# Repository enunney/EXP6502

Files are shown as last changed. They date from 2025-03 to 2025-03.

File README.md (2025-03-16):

# EXP6502
6502 based expandable computer.

<p align="center">
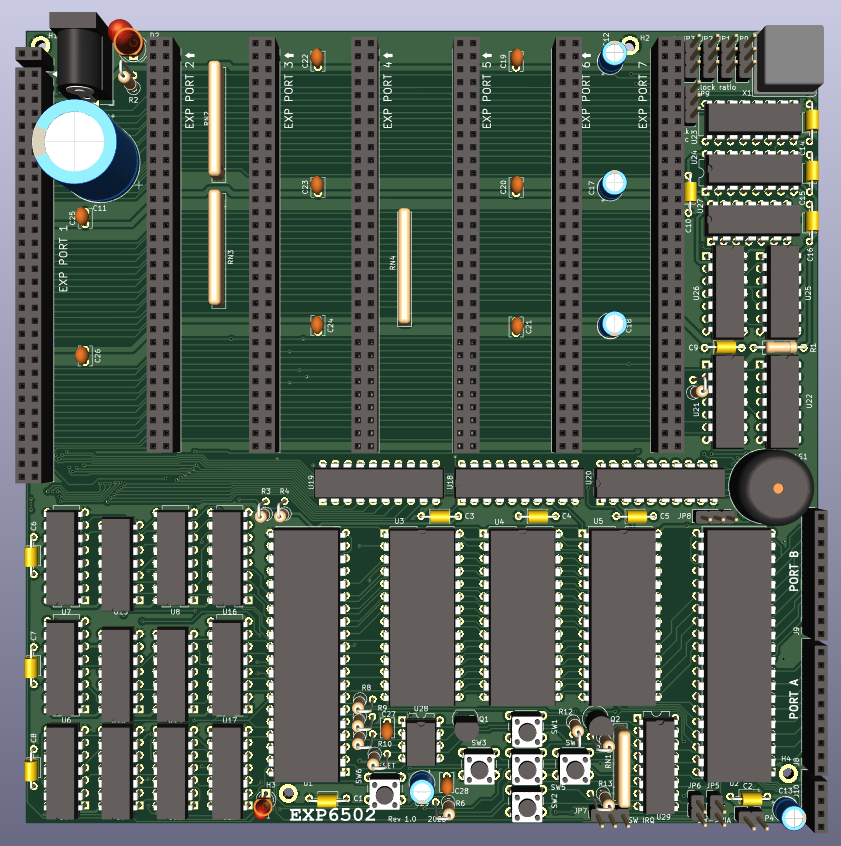
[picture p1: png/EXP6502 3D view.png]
  
</p>

## Specifications

- W65C02 CPU @ 8MHz
- 64 kB SRAM
- 32 kB EEPROM (read only)
- 7 general purpose expansion ports
- Bank switching with access to up to 160 kB of memory
- W65C22 Versatile Interface Adapter
- Software controllable glitchless clock switching (8 MHz / fraction of 8 MHz)
- Built-in beeper speaker and LED
- 5 built-in push buttons with interrupt capability

## Architecture
### Block diagram

<p align="center">
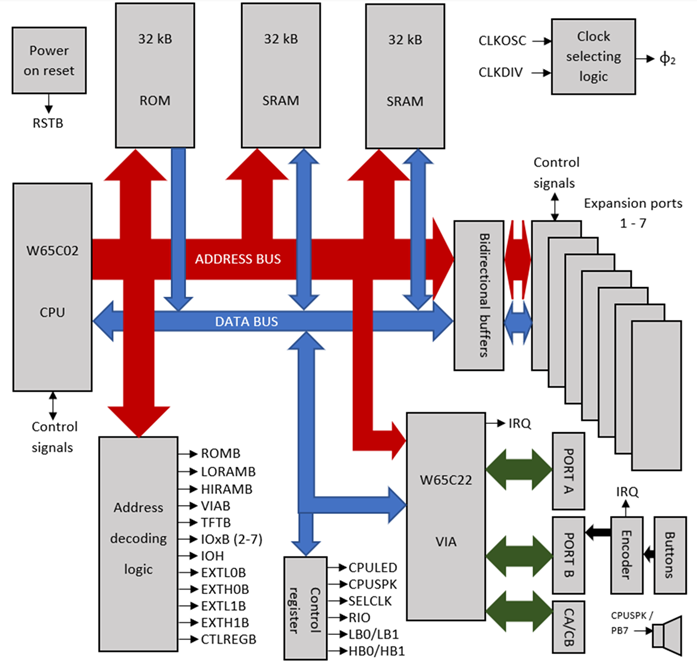
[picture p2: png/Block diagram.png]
  
</p>

The CPU address and data buses are directly connected to the onboard memory and peripherals. Tristate buffers isolate the local buses from the expansion ports.
CMOS logic ICs decode the address bus as well as the status of the control register to provide control signals for each component.

### Memory map

<p align="center">
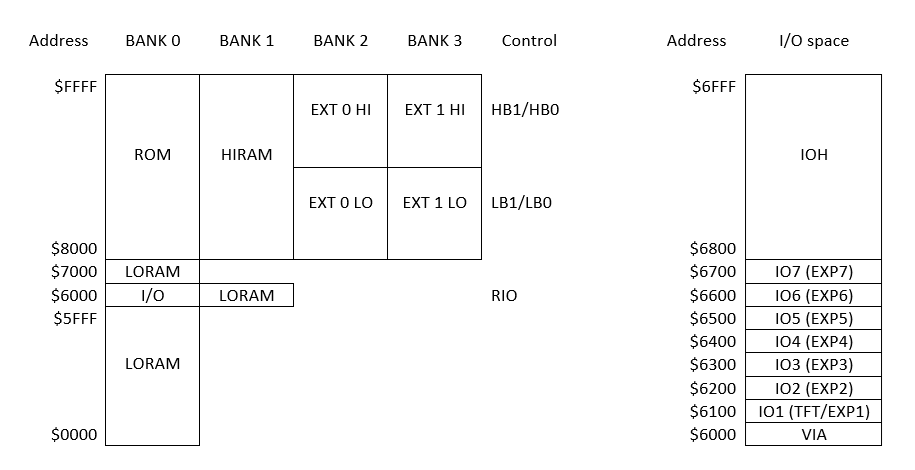
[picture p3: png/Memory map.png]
  
</p>

The lower half of the address space contains 32 kB of RAM (the low RAM) and the I/O space. The I/O space sits
between $6000 and $6FFF. It can be switched out to access the 4 kB of RAM located at the same memory addresses.

The I/O space is made of two parts. The bottom one is divided in 8 pages, each of these controlling one I/O
peripheral. The first I/O page is reserved for the built in VIA. The 7 others are each attributed to a different
expansion port. The top part of the I/O space, IOH, is available on every expansion port, in case they need more I/O
addresses.

The upper half of the address space is divided in two blocks, each of them is multiplied in 4 banks. One bank in each
block can be selected at a time, and the two blocks can have a different bank selected.

The first bank gives access to the ROM of the computer, it is selected by default at start up or after reset.
The second one gives access to 32 kB of RAM, the high RAM.
The third and fourth ones give access to memory placed on the expansion ports. The chip select signals of these
banks are accessible on any expansion port.

The bank switching in the lower half of the address space is controlled by the RIO signal, bit 3 of the control register.
It allows switching the window between $6000 and $6FFF to the I/O space, when RIO is low, or to the low RAM,
when RIO is high.

The bank switching in the upper half of the address space is controlled by the LB0, LB1, HB0 and HB1 signals, bits 4 to
7 of the control register. The bits LB0 and LB1 control the bank switching in the bottom block (\$8000 to \$BFFF). HB0
and HB1 control the switching in the top block (\$C000 to \$FFFF).
- The first bank, bank 0, is mapped to the ROM, in the two blocks.
- The bank 1, is mapped in the two blocks to the high RAM.
- The bank 2 enables the external high memory 0, EXT0HI in the top block and the external low memory 0, EXT0LO in the bottom block.
- The bank 3 enables the external high memory 1, EXT1HI in the top block and the external low memory 1, EXT1LO in the bottom block.

### Expansion port

The computer has 7 general purpose expansion ports.
They give access to buffered versions of the address and data buses of the computer, to various control signals of
the microprocessor and to the selecting signals for the external memory banks. They also have access to some pins
of the VIA.

The expansion ports have access to the main clock, φ2, as well as the oscillator clock and the divided clock. This
feature allows an expansion card to keep using one of these clocks while the computer has switched to another one,
for instance for slow peripherals that couldn’t handle the oscillator frequency. It is worth noting that the CPU can’t
access these peripherals while the clocks are different, as it would have an unpredictable behavior.

Any expansion port can take control of the computer, by setting low the EXTCTLB signal, which disables the busses of
the CPU and reverses the direction of the address and data buffers. The RDY signal should be put low at the same
time to effectively halt the CPU.

The expansion port 1 has an additional two pins header socket placed next to it. It is intended to be connected to the
read and write pins of a TFT LCD screen (controlled by an ILI9341 IC or compatible) for write only access when the
port 1 is connected to such a screen.

The pinout of the expansion ports and the function of each pin can be found in the technical reference manual.

### Control register

The control register allows the software to switch the memory banks, to change the clock speed and to directly
control an LED and the beeper speaker.
It is located at address $0000 of the address space, in the zero page of the 6502 microprocessor, to allow faster
access.
The function of each of its bits is given below:

- Bit 0: CPULED
→ Control signal for the built in LED.
- Bit 1: CPUSPK
→ Can be connected to the built in beeper speaker.
- Bit 2: SELCLK
→ Control the current clock source for the main clock φ2.
- Bit 3: RIO
→ Select the I/O space or the low RAM between $6000 and $6FFF.
- Bit 4: LB0
→ LSB of the number of the selected bank in the bottom block of the upper half of the address space.
- Bit 5: LB1
→ MSB of the number of the selected bank in the bottom block of the upper half of the address space.
- Bit 6: HB0
→ LSB of the number of the selected bank in the top block of the upper half of the address space.
- Bit 7: HB1
→ MSB of the number of the selected bank in the top block of the upper half of the address space.

More details are available in the technical reference manual.

### Clocking

The main clock of the computer, φ2, can be switched between two different sources: the oscillator clock or a divided
version of the oscillator clock.

The default oscillator frequency is 8 MHz. A counter and a JK flip-flop generate a divided version of this clock. The
dividing ratio can be configured with 4 jumpers on the computer. The ratio is between /2 when the value configured
by the jumpers is set to 15, and /32 when the value is 0.
The dividing ratio follows the formula: R = 2*(16-n), where n is the value configured with the jumpers.

The oscillator clock can also be replaced by an external clock, placed on any of the expansion port. The external clock
must be selected with the corresponding jumper.

### I/O

The computer has a built in Versatile Interface Adapter (VIA), of which the two GPIO ports are accessible on 2 pin
header sockets. The CA1, CA2, CB1 and CB2 pins of the VIA are accessible on another pin header socket, as well as on
every expansion port.

The bits 3, 4 and 5 of the PORT B of the VIA can be connected to an 8 to 3 priority encoder with jumpers. The inputs
of the encoder are driven by 5 push buttons. When a button is pressed, the corresponding code is sent to the VIA.
The encoder can generate an interrupt either directly or through the CA2 pin of the VIA, depending on the jumper
configuration.

The VIA can also drive the built in beeper speaker when the jumper connected to the speaker is set accordingly.
The control register is connected to the red LED and can be connected to the speaker.

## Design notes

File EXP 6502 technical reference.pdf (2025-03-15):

# EXP 6502

# Technical reference

v1.0 | 12/04/2023 | Eric Nunney

## Table of contents

## I. Specifications II. Architecture

### 1. Block diagram 2. Memory map 3. Bank switching 4. Control register 5. Clock switching 6. Expansion ports 7. Built-in I/O

## III. Schematic diagram

### 1. CPU and memory 2. Address decoding

3. I/O

### 4. Expansion ports 5. Clock and reset 6. Power

## IV. PCB layout

### 1. Top layer 2. Bottom layer 3. Jumper configuration

# I. Specifications

- W65C02 microprocessor at up to 8 MHz (MOS 6502 compatible)
- 64 kB SRAM
- 32 kB EEPROM (read only)
- W65C22 Versatile Interface Adapter
- 7 general purpose expansion ports
- Bank switching, access to up to 160 kB of memory
- Software controllable glitchless clock switching (8 MHz / configurable fraction of 8 MHz)
- Power-on reset circuit
- Built-in beeper speaker
- Built-in LED
- 5 built-in push buttons with interrupt capability
- Single 5V DC power input
- CMOS only logic ICs (higher speed / less power)

# II. Architecture

## 1. Block diagram

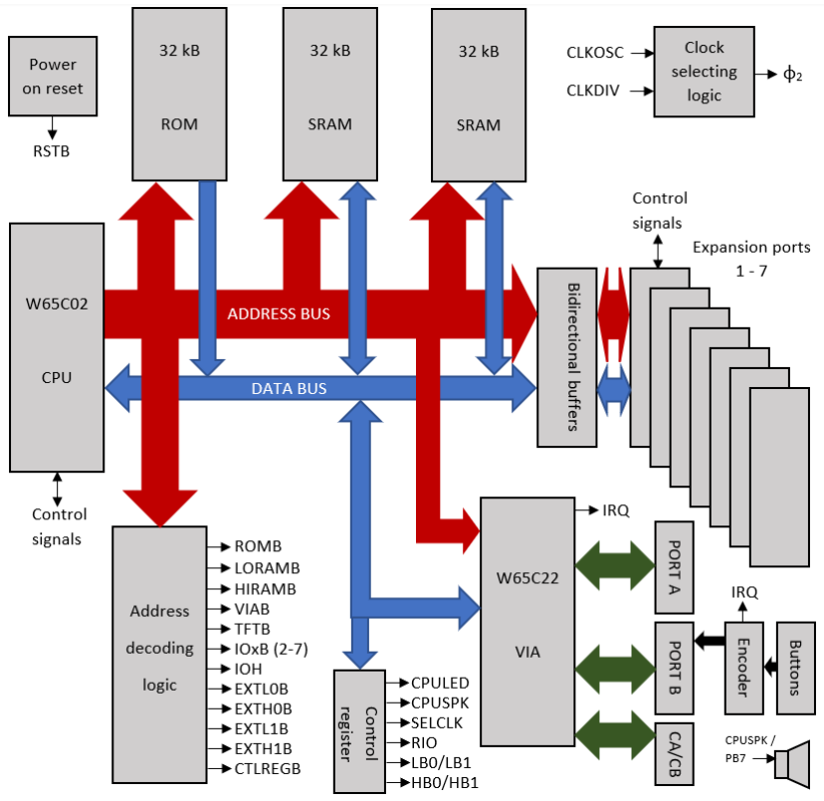
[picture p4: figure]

## 2. Memory map

Address | BANK 0 | BANK 1 | BANK 2 | BANK 3 | Control | Address | I/O space

$FFFF

ROM | HIRAM
EXT 0 HI | EXT 1 HI

$6FFF

IOH

HB1/HB0

EXT 0 LO | EXT 1 LO | LB1/LB0
$8000 | | | | $6800
$7000 | LORAM | | | $6700 | IO7 (EXP7)
$6000 | I/O | LORAM | RIO | $6600 | IO6 (EXP6)
$5FFF
| LORAM | | | $6500 | IO5 (EXP5)
| | | | $6400 | IO4 (EXP4)
| | | | $6300 | IO3 (EXP3)
| | | | $6200 | IO2 (EXP2)
| | | | $6100 | IO1 (TFT/EXP1)
$0000 | | | | $6000 | VIA

The lower half of the address space contains 32 kB of RAM (the low RAM) and the I/O space. The I/O space sits between $6000 and $6FFF. It can be switched out to access the 4 kB of RAM located at the same memory addresses.

The I/O space is made of two parts. The bottom one is divided in 8 pages, each of these controlling one I/O peripheral. The first I/O page is reserved for the built in VIA. The 7 others are each attributed to a different expansion port. The top part of the I/O space, IOH, is available on every expansion port, in case they need more I/O addresses.

The upper half of the address space is divided in two blocks, each of them is multiplied in 4 banks. One bank in each block can be selected at a time, and the two blocks can have a different bank selected.

The first bank gives access to the ROM of the computer, it is selected by default at start up or after reset.

The second one gives access to 32 kB of RAM, the high RAM.

The third and fourth ones give access to memory placed on the expansion ports. The chip select signals of these banks are accessible on any expansion port.

## 3. Bank switching

The bank switching in the lower half of the address space is controlled by the RIO signal, bit 3 of the control register. It allows switching the window between $6000 and $6FFF to the I/O space, when RIO is low, or to the low RAM, when RIO is high.

The bank switching in the upper half of the address space is controlled by the LB0, LB1, HB0 and HB1 signals, bits 4 to 7 of the control register. The bits LB0 and LB1 control the bank switching in the bottom block ($8000 to $BFFF). HB0 and HB1 control the switching in the top block ($C000 to $FFFF).

The first bank, bank 0, is mapped to the ROM, in the two blocks. It is enabled in the bottom block when LB1 = 0 and LB0 = 0, and in the top block when HB1 = 0 and HB0 = 0.

The bank 1, is mapped in the two blocks to the high RAM. It is enabled in the bottom block when LB1 = 0 and LB0 = 1, and in the top block when HB1 = 0 and HB0 = 1.

The bank 2 enables the external high memory 0, EXT0HI in the top block when HB1 = 1 and HB0 = 0. It enables the external low memory 0, EXT0LO when LB1 = 1 and LB0 = 0.

The bank 3 enables the external high memory 1, EXT1HI in the top block when HB1 = 1 and HB0 = 1. It enables the external low memory 1, EXT1LO when LB1 = 1 and LB0 = 1.

## 4. Control register

The control register allows the software to switch the memory banks, to change the clock speed and to directly control an LED and the beeper speaker.

It is located at address $0000 of the address space, in the zero page of the 6502 microprocessor, to allow faster access.

The function of each of its bits is given below:

7 | 6 | 5 | 4 | 3 | 2 | 1 | 0
HB1 | HB0 | LB1 | LB0 | RIO | SELCLK | CPUSPK | CPULED

→ Bit 0: CPULED
- Control signal for the built in LED.
→ Bit 1: CPUSPK
- Can be connected to the built in beeper speaker.
→ Bit 2: SELCLK
- Control the current clock source for the main clock φ2.
- | 0: divided clock | 1: Oscillator clock
→ Bit 3: RIO
- Select the I/O space or the low RAM between $6000 and $6FFF.
- | 0: I/O space | 1: low RAM
→ Bit 4: LB0
- LSB of the number of the selected bank in the bottom block of the upper half of the address space. → Bit 5: LB1
- MSB of the number of the selected bank in the bottom block of the upper half of the address space. → Bit 6: HB0
- LSB of the number of the selected bank in the top block of the upper half of the address space.
→ Bit 7: HB1
- MSB of the number of the selected bank in the top block of the upper half of the address space.

## 5. Clock switching

The main clock of the computer, φ2, can be switched between two different sources: the oscillator clock or a divided version of the oscillator clock.

The default oscillator frequency is 8 MHz. A counter and a JK flip-flop generate a divided version of this clock. The dividing ratio can be configured with 4 jumpers on the computer. The ratio is between /2 when the value configured by the jumpers is set to 15, and /32 when the value is 0.

The dividing ratio follows the formula: R = 2*(16-n), where n is the value configured with the jumpers.

The oscillator clock can also be replaced by an external clock, placed on any of the expansion port. The external clock must be selected with the corresponding jumper.

## 6. Expansion ports

The computer has 7 general purpose expansion ports.

They give access to buffered versions of the address and data buses of the computer, to various control signals of the microprocessor and to the selecting signals for the external memory banks. They also have access to some pins of the VIA.

The expansion ports have access to the main clock, φ2, as well as the oscillator clock and the divided clock. This feature allows an expansion card to keep using one of these clocks while the computer has switched to another one, for instance for slow peripherals that couldn’t handle the oscillator frequency. It is worth noting that the CPU can’t access these peripherals while the clocks are different, as it would have an unpredictable behavior.

Any expansion port can take control of the computer, by setting low the EXTCTLB signal, which disables the busses of the CPU and reverses the direction of the address and data buffers. The RDY signal should be put low at the same time to effectively halt the CPU.

The expansion port 1 has an additional two pins header socket placed next to it. It is intended to be connected to the read and write pins of a TFT LCD screen (controlled by an ILI9341 IC or compatible) for write only access when the port 1 is connected to such a screen.

The following table is a pinout of an expansion port. They are all identical excepted the I/O select line IOxB which is different for each port, allowing to access each expansion card as a different I/O peripheral.

GND | 2 | 1 | GND
VDD | 4 | 3 | VDD
AE15 | 6 | 5 | IOxB
AE14 | 8 | 7 | CLKOSC
AE13 | 10 | 9 | IOHB
AE12 | 12 | 11 | CLKDIV
AE11 | 14 | 13 | RW
AE10 | 16 | 15 | PHI2
AE9 | 18 | 17 | RSTB
AE8 | 20 | 19 | PHI1
GND | 22 | 21 | GND
VDD | 24 | 23 | VDD
GND | 26 | 25 | GND
AE7 | 28 | 27 | DE7
AE6 | 30 | 29 | DE6
AE5 | 32 | 31 | DE5
AE4 | 34 | 33 | DE4
AE3 | 36 | 35 | DE3
AE2 | 38 | 37 | DE2
AE1 | 40 | 39 | DE1
AE0 | 42 | 41 | DE0
VDD | 44 | 43 | VDD
GND | 46 | 45 | GND
NMIB | 48 | 47 | IRQEXTB
RDY | 50 | 49 | EXTCTLB
EXTCLK | 52 | 51 | MLB
SYNC | 54 | 53 | VPB
EXTL0B | 56 | 55 | EXTH0B
EXTL1B | 58 | 57 | EXTH1B
CA1 | 60 | 59 | CA2
CB1 | 62 | 61 | CB2
GND | 64 | 63 | GND

The function of each of the pins is given below:

Signal | Active when | Function
AE0 to AE15 | X | buffered address bus
DE0 to DE7 | X | buffered data bus
IOxB | LOW | enabled when the corresponding memory page is accessed
IOHB | LOW | enabled when the top half of the I/O space is accessed
EXTL0B | LOW | enabled when the bottom bloc of bank 2 is accessed
EXTL1B | LOW | enabled when the bottom bloc of bank 3 is accessed
EXTH0B | LOW | enabled when the top bloc of bank 2 is accessed
EXTH1B | LOW | enabled when the top bloc of bank 3 is accessed
CLKOSC | X | Clock at the output of the crystal oscillator
CLKDIV | X | Divided clock
PHI2 | X | Main clock (CPU clock)
PHI1 | X | Inverted version of the main clock, generated by the CPU
EXTCLK | X | Input for an eventual external clock
RSTB | LOW | Reset signal
RW | X | Read (1) /write (0) signal
IRQEXTB | LOW | Interrupt request signal
NMIB | LOW | Non maskable interrupt request signal
EXTCTLB | LOW | Disables the data busses of the CPU and change the direction of the buffers
RDY | HIGH | When put LOW, halts the CPU. When it goes low indicate a WAI instruction
MLB | LOW | Active during the last three cycles of read-modify-write instructions of the CPU
VPB | LOW | Active when the CPU is retrieving interrupt vectors from memory
SYNC | HIGH | Active when the CPU is fetching an instruction opcode
CA1 | X | CA1 pin of the VIA
CA2 | X | CA2 pin of the VIA
CB1 | X | CB1 pin of the VIA
CB2 | X | CB2 pin of the VIA
VDD | X | +5V DC
GND | X | Ground

## 7. Built-in I/O

The computer has a built in Versatile Interface Adapter (VIA), of which the two GPIO ports are accessible on 2 pin header sockets. The CA1, CA2, CB1 and CB2 pins of the VIA are accessible on another pin header socket, as well as on every expansion port.

The bits 3, 4 and 5 of the PORT B of the VIA can be connected to an 8 to 3 priority encoder with jumpers. The inputs of the encoder are driven by 5 push buttons. When a button is pressed, the corresponding code is sent to the VIA. The encoder can generate an interrupt either directly or through the CA2 pin of the VIA, depending on the jumper configuration.

The VIA can also drive the built in beeper speaker when the jumper connected to the speaker is set accordingly.

The control register is connected to the red LED and can be connected to the speaker.

# III. Schematic diagram

## 1. CPU and memory

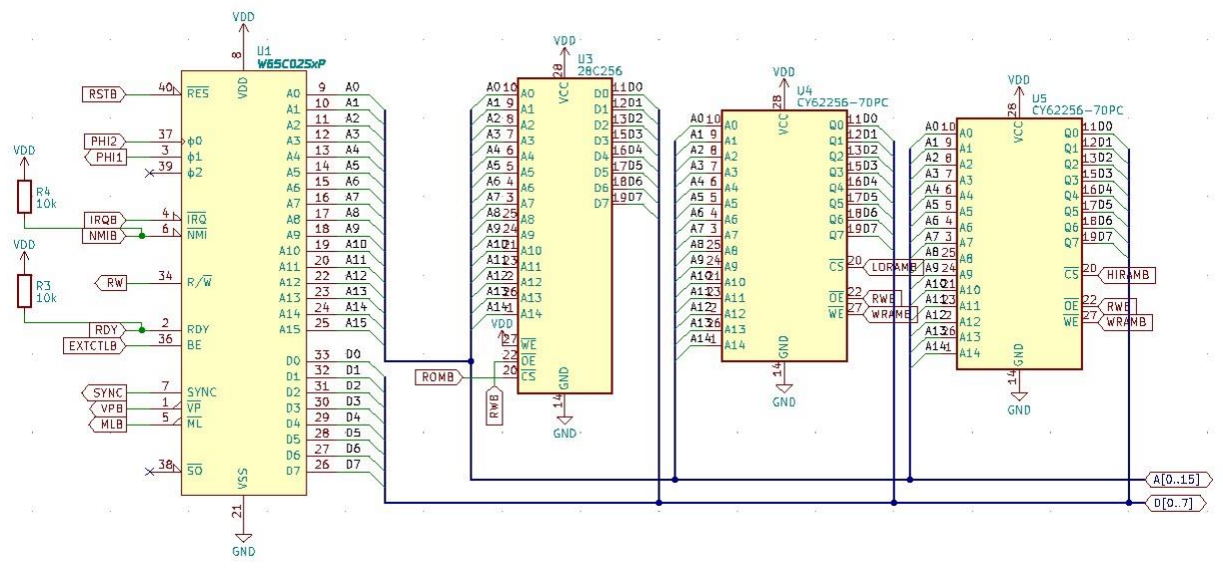
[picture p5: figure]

## 2. Address decoding

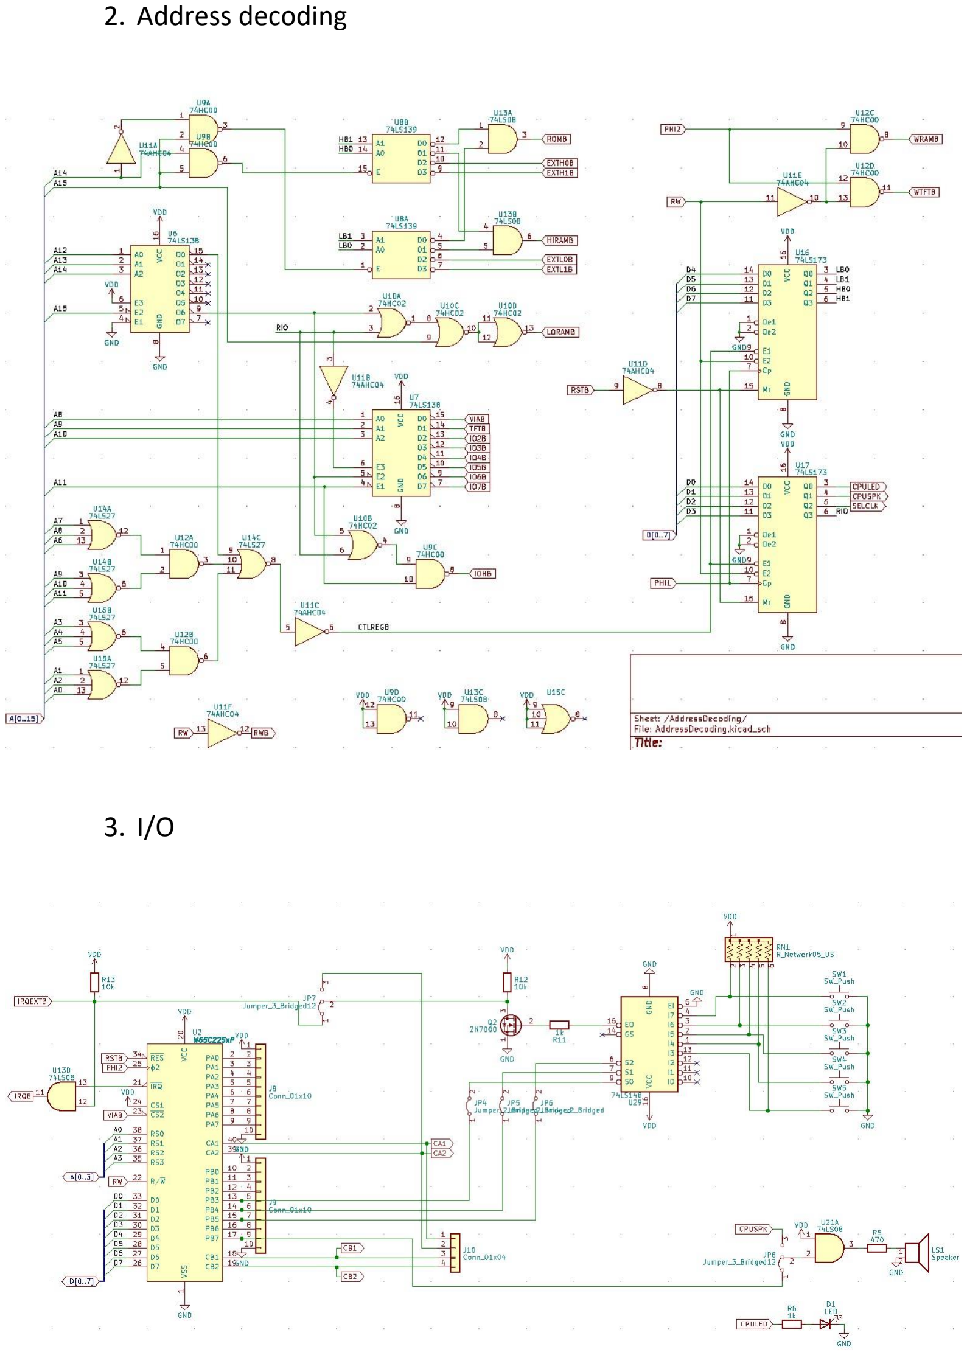
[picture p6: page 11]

3. I/O

## 4. Expansion ports

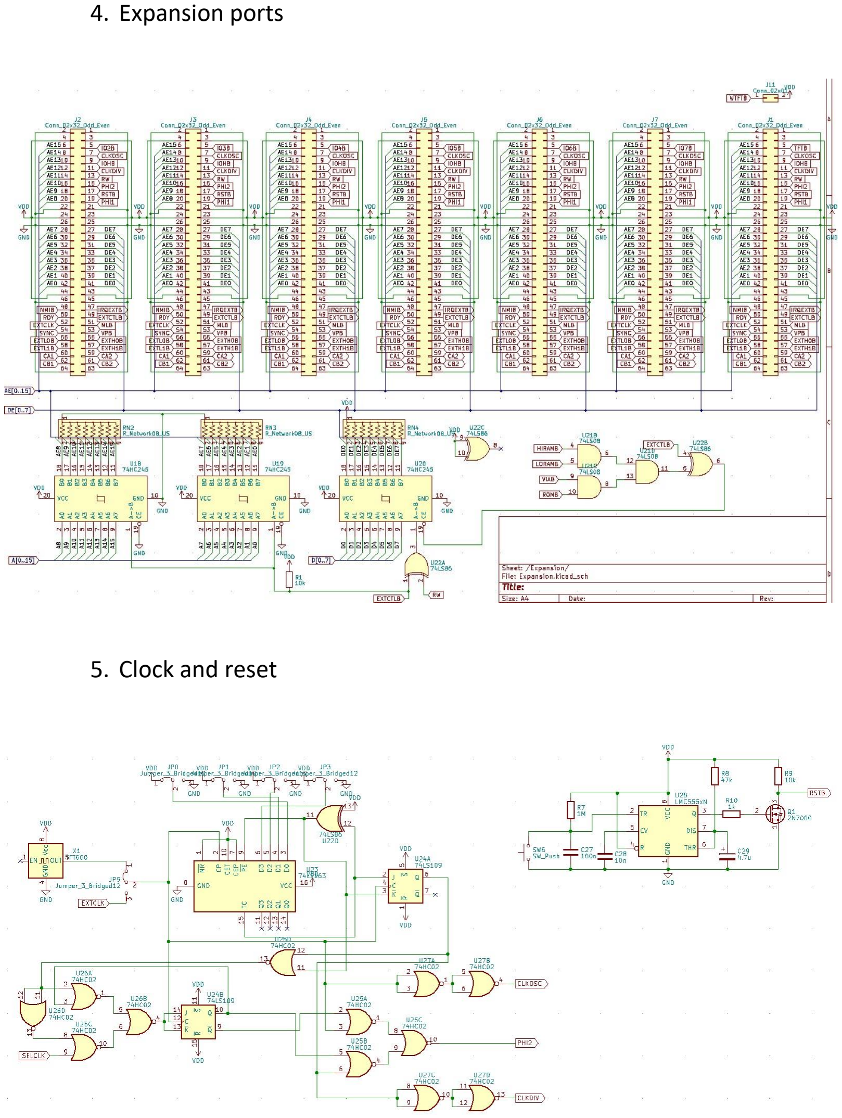
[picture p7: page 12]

## 5. Clock and reset

## 6. Power

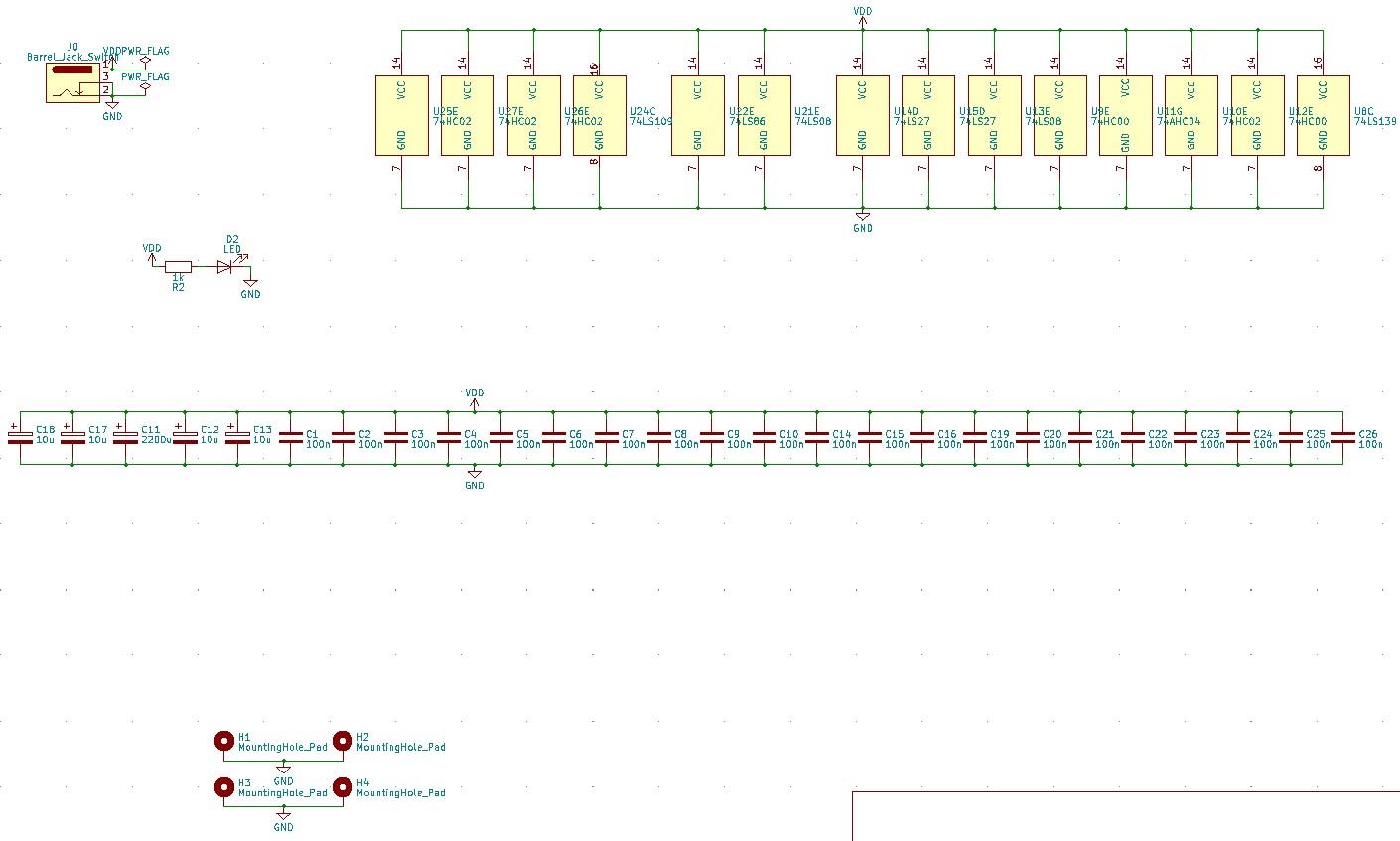
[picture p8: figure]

# IV. PCB layout

## 1. Top layer

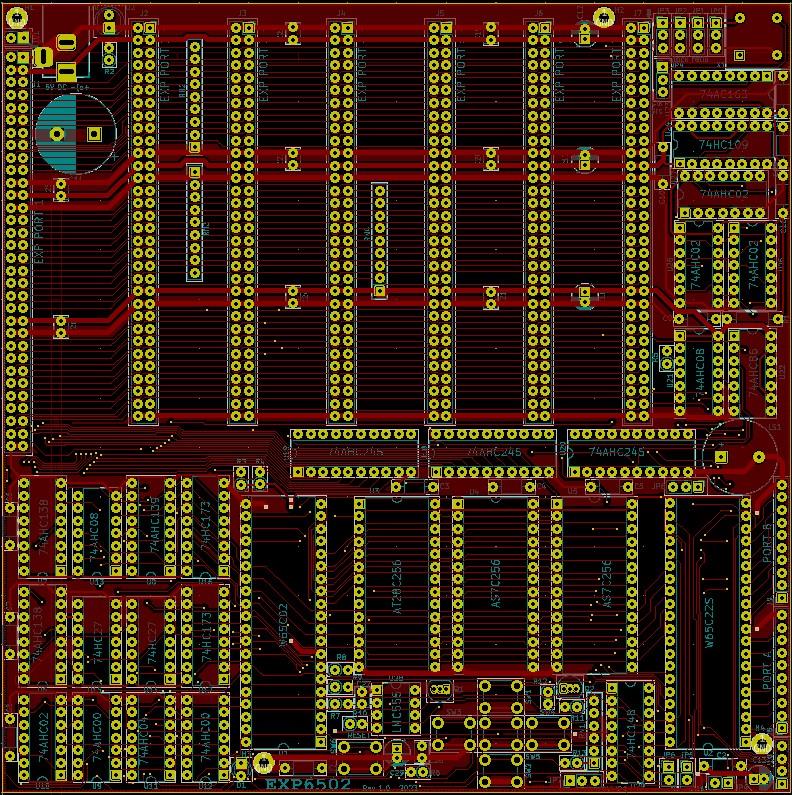
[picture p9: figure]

## 2. Bottom layer

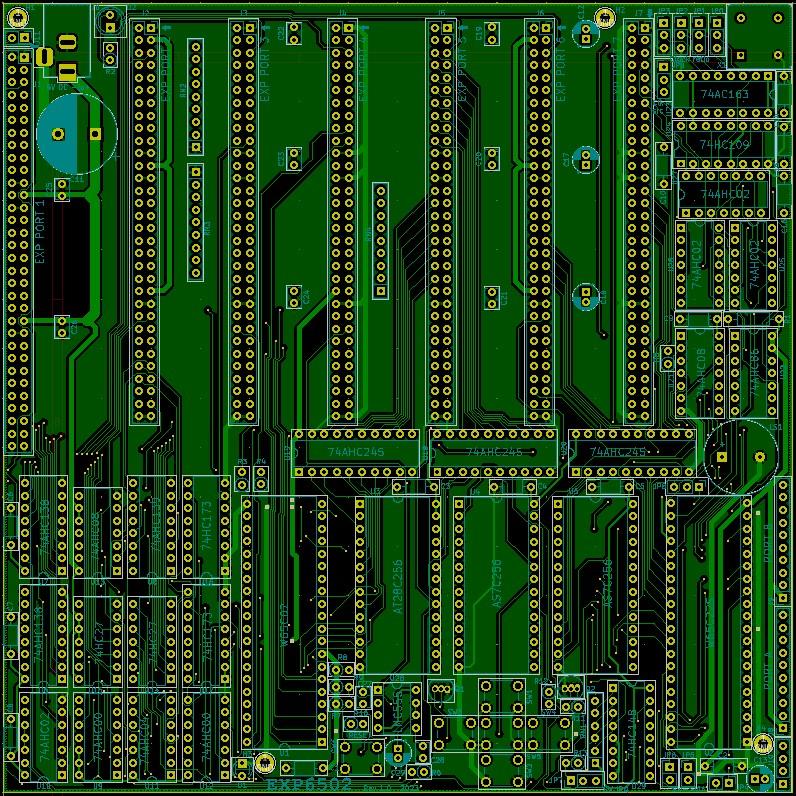
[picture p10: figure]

## 3. Jumper configuration

The following table explains the function of each jumper on the computer:

Jumper | Connection | Function
JP0 | 1-2 | The bit 0 of the value loaded in the divider counter at each new CLKDIV cycle is HIGH
| 2-3 | The bit 0 of the value loaded in the divider counter at each new CLKDIV cycle is LOW
JP1 | 1-2 | The bit 1 of the value loaded in the divider counter at each new CLKDIV cycle is HIGH
| 2-3 | The bit 1 of the value loaded in the divider counter at each new CLKDIV cycle is LOW
JP2 | 1-2 | The bit 2 of the value loaded in the divider counter at each new CLKDIV cycle is HIGH
| 2-3 | The bit 2 of the value loaded in the divider counter at each new CLKDIV cycle is LOW
JP3 | 1-2 | The bit 3 of the value loaded in the divider counter at each new CLKDIV cycle is HIGH
| 2-3 | The bit 3 of the value loaded in the divider counter at each new CLKDIV cycle is LOW
JP4 | None | Open connection
| 1-2 | Connect output S0 of the encoder to the pin 3 of the PORT B of the VIA
JP5 | None | Open connection
| 1-2 | Connect output S1 of the encoder to the pin 4 of the PORT B of the VIA
JP6 | None | Open connection
| 1-2 | Connect output S2 of the encoder to the pin 6 of the PORT B of the VIA
JP7 | 1-2 | The encoder directly drives the IRQEXTB signal
| 2-3 | The encoder is connected to the CA2 pin of the VIA, to trigger an interrupt
JP8 | 1-2 | The speaker is connected to the pin 7 of the PORT B of the VIA (timer 1 output)
| 2-3 | The speaker is connected to the pin 1 of the control register, CPUSPK
JP9 | 1-2 | The CLKOSC clock comes from the built in crystal oscillator
| 2-3 | The CLKOSC clock is connected to the EXTCLK pin of the expansion connectors

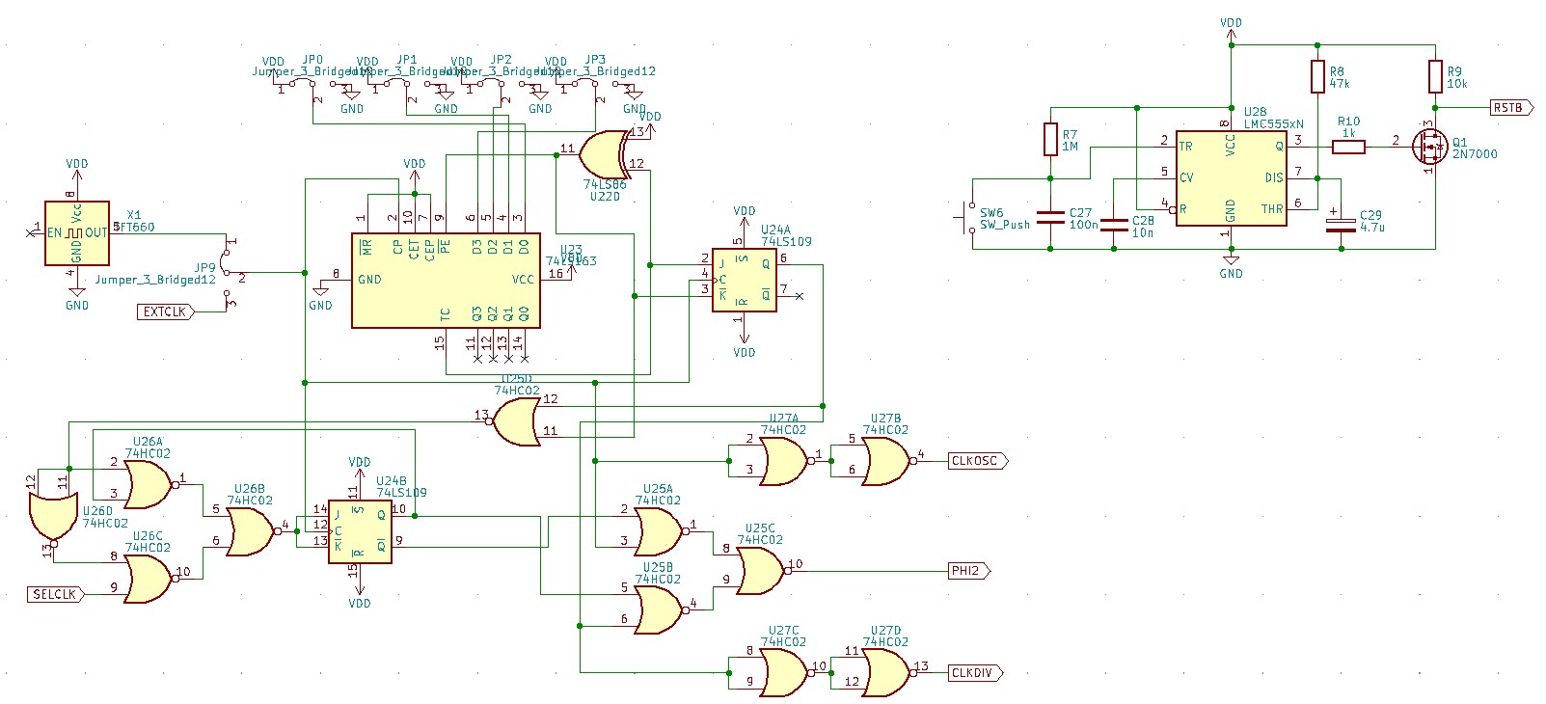
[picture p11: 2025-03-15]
Schémas/Clock and reset.jpg

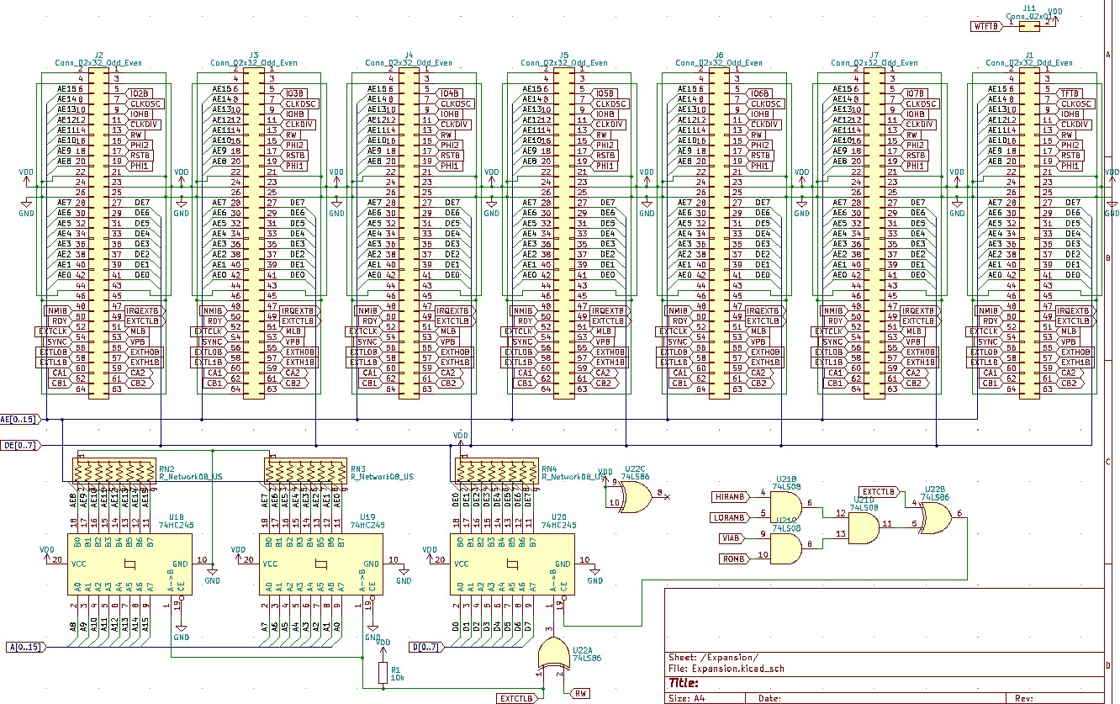
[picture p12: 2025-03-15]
Schémas/Expansion.jpg

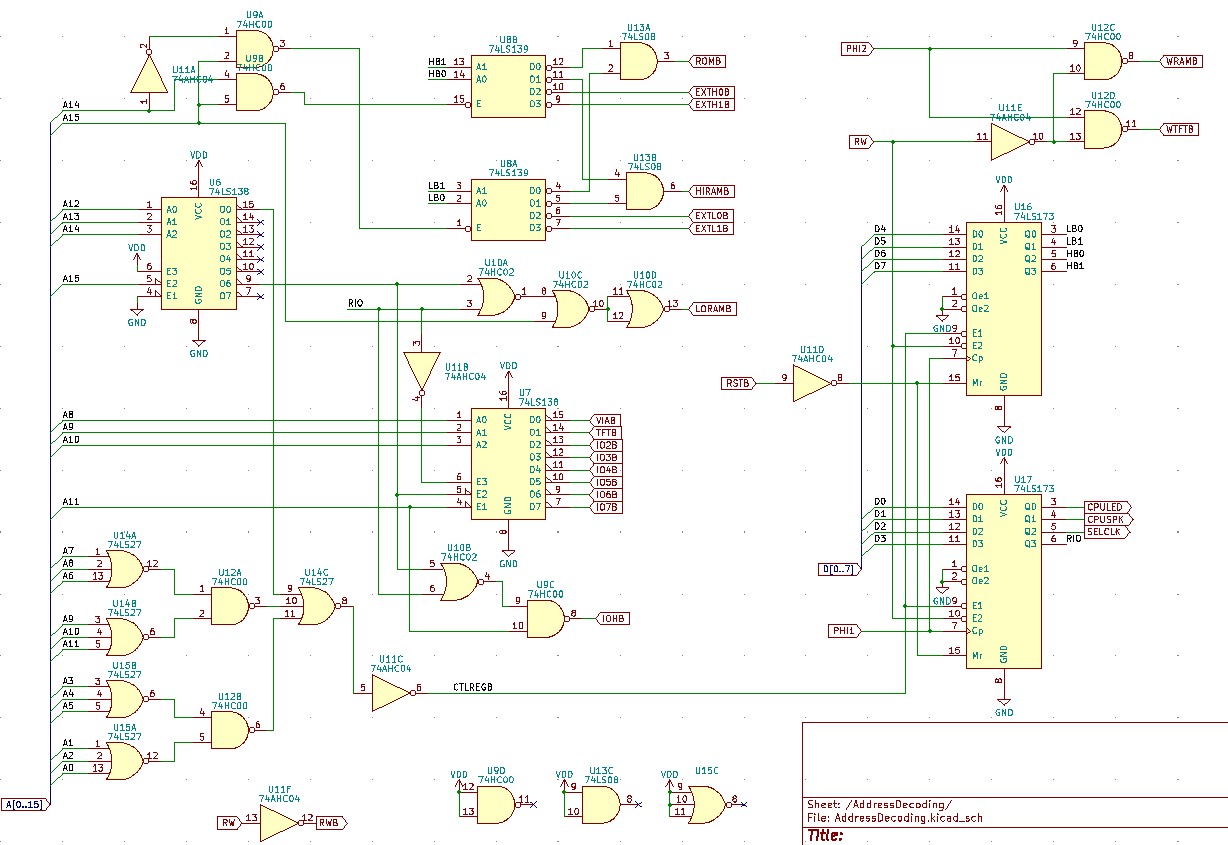
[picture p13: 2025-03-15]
Schémas/Address decoding.jpg

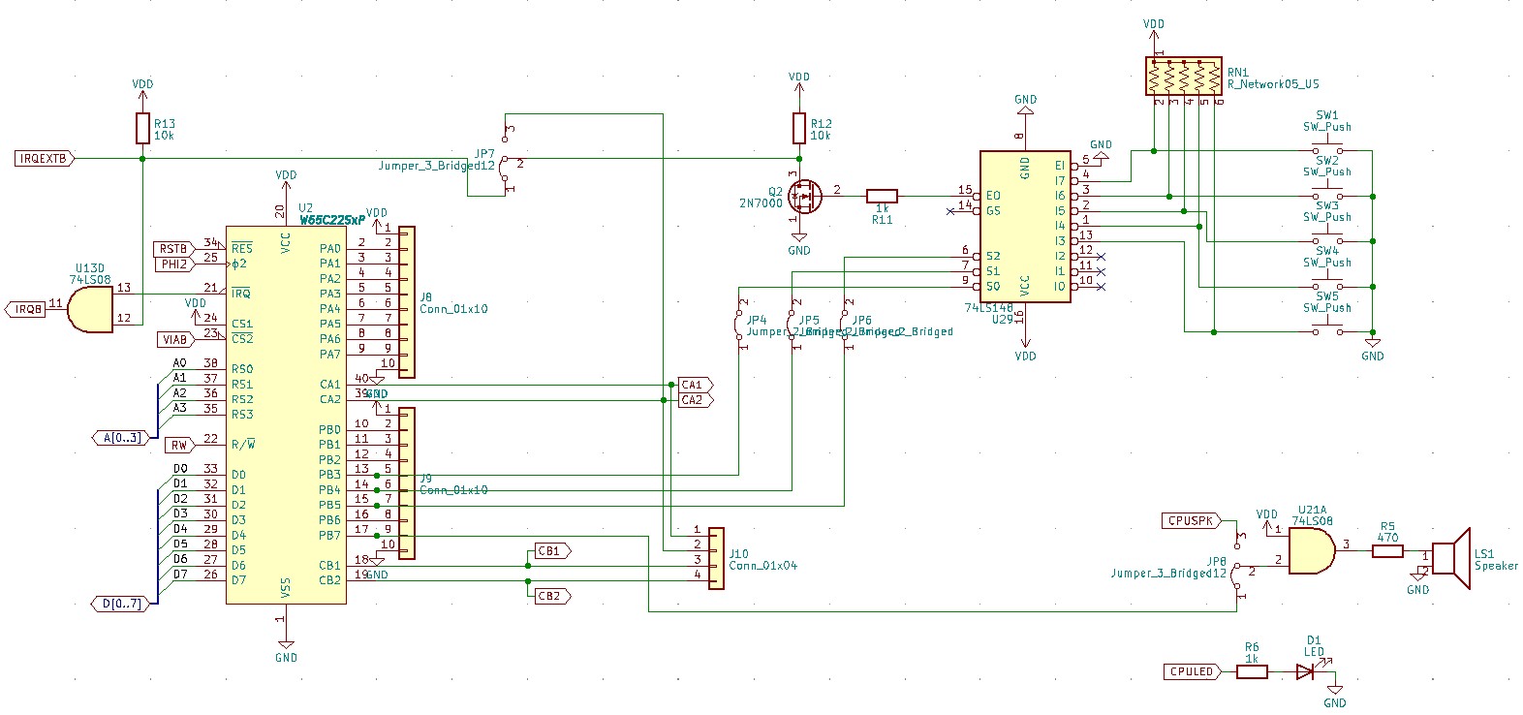
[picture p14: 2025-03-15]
Schémas/IO.jpg

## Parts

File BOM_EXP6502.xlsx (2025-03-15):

Nom | Fonction | Quantité | Prix unitaire | Prix total | Commandé
ICs
W65C02 | 6502 CPU | 1 | 10.81 | 10.81 | x
W65C22S | 6522 VIA | 1 | 10.21 | 10.21 | x
AT28S256 | 32K*8 EEPROM | 1 | 9.8 | 9.8 | x
AS7C256B | 32K*8 SRAM | 2 | 2.58 | 5.16 | x
74AHC00 | 4 2-input NAND | 2 | 0.611 | 1.222 | x
74AHC02 | 4 2-input NOR | 4 | 0.79 | 3.16 | x
74AHC04 | Hex inverter | 1 | 0.62 | 0.62 | x
74AHC08 | 4 2-input AND | 2 | 0.921 | 1.842 | x
74HC27 | 3 3-input NOR | 2 | 0.564 | 1.128 | x
74AHC86 | 4 2-input XOR | 1 | 0.564 | 0.564 | x
74hc109 | Dual J K\ flip-flop | 1 | 0.799 | 0.799 | x
74AHC138 | 3 to 8 decoder | 2 | 0.639 | 1.278 | x
74AHC139 | Dual 2 to 4 decoder | 1 | 0.639 | 0.639 | x
74HC148 | 8 to 3 priority encoder | 1 | 0.564 | 0.564 | x
74AC163 | 4-bit sych counter | 1 | 0.808 | 0.808 | x
74HC173 | 4 D flip-flop | 2 | 0.649 | 1.298 | x
74HC245 | 8 bidir tristate buffer | 3 | 0.752 | 2.256 | x
LMC555 | 555 timer (CMOS) | 1 | 1.58 | 1.58 | x
Sous-total ICs |  | 29 |  | 53.738
Sockets
40-pin DIP |  | 2 | 1.04 | 2.08 | x
28-pin DIP |  | 3 | 0.771 | 2.313 | x
28-pin ZIF |  | 1 | 10.7 | 10.7 | x
20-pin DIP |  | 3 | 0.517 | 1.551 | x
16-pin DIP |  | 8 | 0.282 | 2.256 | x
14-pin DIP |  | 12 | 0.263 | 3.156 | x
8-pin DIP |  | 1 | 0.254 | 0.254 | x
8-pin crystal oscillator socket | 4 empty pins | 1 | 0.902 | 0.902 | x
Sous-total sockets |  | 31 |  | 23.212
Résistances
470 resistor |  | 1 | 0.02 | 0.02 | x
1k resistor |  | 9 | 0.02 | 0.18 | x
10k resistor |  | 1 | 0.02 | 0.02 | x
47k resistor |  | 1 | 0.02 | 0.02 | x
1M resistor |  | 1 | 0.02 | 0.02 | x
Sous-total résistances |  | 13 |  | 0.26
Condensateurs
10n radial ceramic capacitor |  | 1 | 0.207 | 0.207 | x
100n axial ceramic capacitor |  | 13 | 0.33 | 4.29 | x
100n radial ceramic capacitor |  | 9 | 0.101 | 0.909 | x
4,7µ electrolytic capacitor |  | 1 | 0.094 | 0.094 | x
10µ electrolytic capacitor |  | 4 | 0.094 | 0.376 | x
2200µ electrolytic capacitor |  | 1 | 3.43 | 3.43 | x
Sous-total condensateurs |  | 29 |  | 9.306
Connecteurs
5,5 mm barrel jack |  | 1 | 1.01 | 1.01 | x
2x32 pin header socket 2,54 mm pitch |  | 7 | 1.105 | 7.735
Sous-total connecteurs |  | 8 |  | 8.745
Autres
8 MHz can oscillator |  | 1 | 2.96 | 2.96 | x
8 10k resistor network |  | 3 | 0.555 | 1.665 | x
5 10k resistor network |  | 1 | 0.62 | 0.62 | x
2N7000 | N-channel MOSFET | 2 | 0.05 | 0.1 | x
6mm tactile switch |  | 6 | 0.06 | 0.36 | x
15mm speaker |  | 1 | 3.78 | 3.78 | x
3mm LED |  | 1 | 0.02 | 0.02 | x
5mm LED |  | 1 | 0.02 | 0.02 | x
2,54mm pitch pin header |  | 1 | 0.2 | 0.2 | x
Sous-total autres |  | 17 |  | 9.725
TOTAL |  | 127 |  | 104.986

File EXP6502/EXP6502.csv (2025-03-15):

Id | Designator | Footprint | Quantity | Designation | Supplier and ref
1 | R5 | R_Axial_DIN0207_L6.3mm_D2.5mm_P2.54mm_Vertical | 1 | 220
2 | SW6,SW5,SW4,SW3,SW2,SW1 | SW_PUSH_6mm | 6 | SW_Push
3 | R2,R13,R9,R14,R4,R11,R10,R3 | R_Axial_DIN0207_L6.3mm_D2.5mm_P2.54mm_Vertical | 8 | 1k
4 | U15,U14 | DIP-14_W7.62mm | 2 | 74LS27
5 | J11 | PinSocket_2x01_P2.54mm_Vertical | 1 | Conn_02x01
6 | U5,U4 | DIP-28_W15.24mm | 2 | CY62256-70PC
7 | U3 | DIP-28_W15.24mm | 1 | 28C256
8 | J4,J6,J7,J2,J5,J1,J3 | PinSocket_2x32_P2.54mm_Vertical | 7 | Conn_02x32_Odd_Even
9 | U11 | DIP-14_W7.62mm | 1 | 74AHC04
10 | U1 | DIP-40_W15.24mm | 1 | W65C02SxP
11 | U29 | DIP-16_W7.62mm | 1 | 74LS148
12 | U2 | DIP-40_W15.24mm | 1 | W65C22SxP
13 | C25,C21,C27,C19,C26,C22,C20,C23,C24 | C_Disc_D3.8mm_W2.6mm_P2.50mm | 9 | 100n
14 | H2,H3,H1,H4 | MountingHole_2.2mm_M2_DIN965_Pad | 4 | MountingHole_Pad
15 | U27,U25,U10,U26 | DIP-14_W7.62mm | 4 | 74HC02
16 | C3,C8,C2,C10,C16,C14,C1,C15,C7,C6,C9,C5,C4 | C_Axial_L3.8mm_D2.6mm_P7.50mm_Horizontal | 13 | 100n
17 | JP3,JP2,JP9,JP7,JP1,JP8,JP0 | PinHeader_1x03_P2.54mm_Vertical | 7 | Jumper_3_Bridged12
18 | R8 | R_Axial_DIN0207_L6.3mm_D2.5mm_P2.54mm_Vertical | 1 | 47k
19 | C13,C12,C17,C18 | CP_Radial_D5.0mm_P2.00mm | 4 | 10u
20 | RN4,RN3,RN2 | R_Array_SIP9 | 3 | R_Network08_US
21 | U19,U20,U18 | DIP-20_W7.62mm | 3 | 74HC245
22 | Q1,Q2 | TO-92_Inline | 2 | 2N7000
23 | U8 | DIP-16_W7.62mm | 1 | 74LS139
24 | JP6,JP5,JP4 | PinHeader_1x02_P2.54mm_Vertical | 3 | Jumper_2_Bridged
25 | U21,U13 | DIP-14_W7.62mm | 2 | 74LS08
26 | U23 | DIP-16_W7.62mm | 1 | 74LS163
27 | RN1 | R_Array_SIP6 | 1 | R_Network05_US
28 | C29 | CP_Radial_D5.0mm_P2.00mm | 1 | C_Polarized
29 | U28 | DIP-8_W7.62mm | 1 | LMC555xN
30 | R7 | R_Axial_DIN0207_L6.3mm_D2.5mm_P2.54mm_Vertical | 1 | 1M
31 | J10 | PinSocket_1x04_P2.54mm_Vertical | 1 | Conn_01x04
32 | U17,U16 | DIP-16_W7.62mm | 2 | 74LS173
33 | U7,U6 | DIP-16_W7.62mm | 2 | 74LS138
34 | U22 | DIP-14_W7.62mm | 1 | 74LS86
35 | LS1 | Buzzer_15x7.5RM7.6 | 1 | Speaker
36 | J8,J9 | PinSocket_1x10_P2.54mm_Vertical | 2 | Conn_01x10
37 | U9,U12 | DIP-14_W7.62mm | 2 | 74HC00
38 | C28 | C_Disc_D3.8mm_W2.6mm_P2.50mm | 1 | 10n
39 | U24 | DIP-16_W7.62mm | 1 | 74LS109
40 | R12 | R_Axial_DIN0207_L6.3mm_D2.5mm_P2.54mm_Vertical | 1 | 10k
41 | D1 | LED_D3.0mm | 1 | LED
42 | R1 | R_Axial_DIN0207_L6.3mm_D2.5mm_P10.16mm_Horizontal | 1 | 1k
43 | X1 | Oscillator_DIP-8 | 1 | TFT660
44 | D2 | LED_D5.0mm | 1 | LED
45 | J0 | BarrelJack_Horizontal | 1 | Barrel_Jack_Switch
46 | C11 | CP_Radial_D16.0mm_P7.50mm | 1 | 2200u

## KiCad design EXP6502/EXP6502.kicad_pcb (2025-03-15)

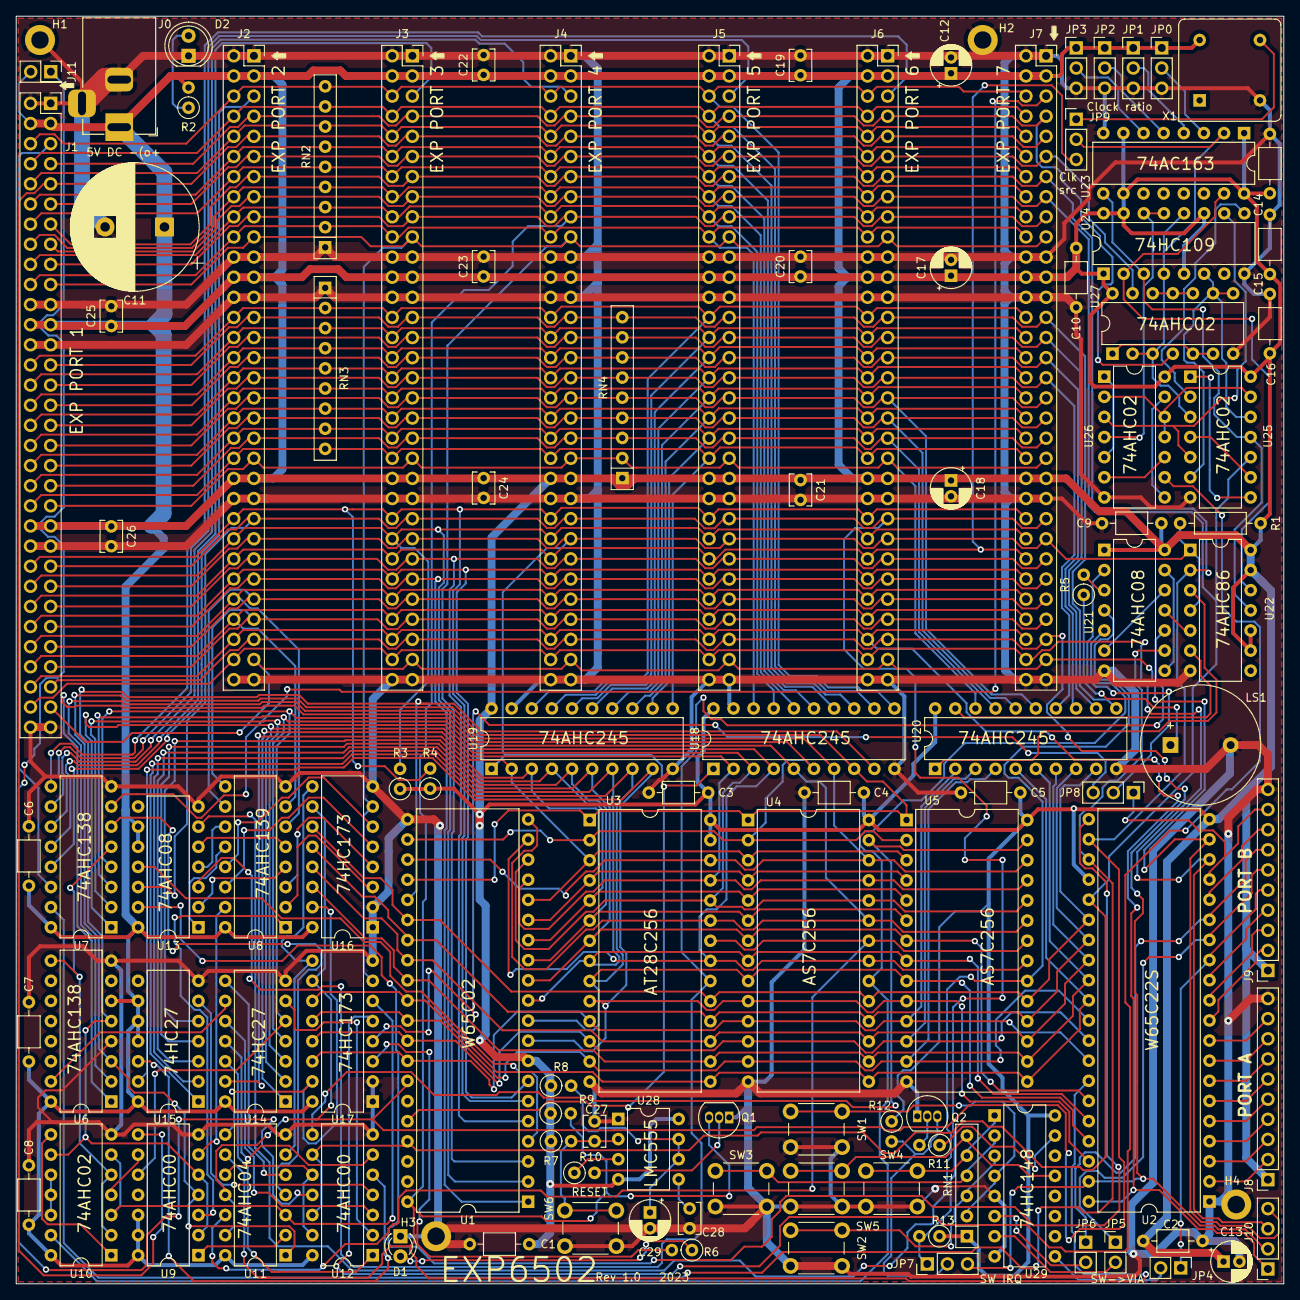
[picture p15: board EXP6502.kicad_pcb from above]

Board: 2 copper layers, 160.0 x 160.0 mm, 113 parts (0 on the bottom side), 182 nets.

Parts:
C1, C2, C3, C4, C5, C6, C7, C8, C9, C10, C14, C15, C16: 100n; C_Axial_L3.8mm_D2.6mm_P7.50mm_Horizontal
C11: 2200u; CP_Radial_D16.0mm_P7.50mm
C12, C13, C17, C18: 10u; CP_Radial_D5.0mm_P2.00mm
C19, C20, C21, C22, C23, C24, C25, C26, C27: 100n; C_Disc_D3.8mm_W2.6mm_P2.50mm
C28: 10n; C_Disc_D3.8mm_W2.6mm_P2.50mm
C29: 4.7u; CP_Radial_D5.0mm_P2.00mm
D1: LED; LED_D3.0mm
D2: LED; LED_D5.0mm
H1, H2, H3, H4: MountingHole_Pad; MountingHole_2.2mm_M2_DIN965_Pad
J0: Barrel_Jack_Switch; BarrelJack_Horizontal
J1, J2, J3, J4, J5, J6, J7: Conn_02x32_Odd_Even; PinSocket_2x32_P2.54mm_Vertical
J8, J9: Conn_01x10; PinSocket_1x10_P2.54mm_Vertical
J10: Conn_01x04; PinSocket_1x04_P2.54mm_Vertical
J11: Conn_02x01; PinSocket_2x01_P2.54mm_Vertical
JP0, JP1, JP2, JP3, JP7, JP8, JP9: Jumper_3_Bridged12; PinHeader_1x03_P2.54mm_Vertical
JP4, JP5, JP6: Jumper_2_Bridged; PinHeader_1x02_P2.54mm_Vertical
LS1: Speaker; Buzzer_15x7.5RM7.6
Q1, Q2: 2N7000; TO-92_Inline
R1: 10k; R_Axial_DIN0207_L6.3mm_D2.5mm_P10.16mm_Horizontal
R2, R6, R10, R11: 1k; R_Axial_DIN0207_L6.3mm_D2.5mm_P2.54mm_Vertical
R3, R4, R9, R12, R13: 10k; R_Axial_DIN0207_L6.3mm_D2.5mm_P2.54mm_Vertical
R5: 470; R_Axial_DIN0207_L6.3mm_D2.5mm_P2.54mm_Vertical
R7: 1M; R_Axial_DIN0207_L6.3mm_D2.5mm_P2.54mm_Vertical
R8: 47k; R_Axial_DIN0207_L6.3mm_D2.5mm_P2.54mm_Vertical
RN1: R_Network05_US; R_Array_SIP6
RN2, RN3, RN4: R_Network08_US; R_Array_SIP9
SW1, SW2, SW3, SW4, SW5, SW6: SW_Push; SW_PUSH_6mm
U1: W65C02SxP; DIP-40_W15.24mm
U2: W65C22SxP; DIP-40_W15.24mm
U3: 28C256; DIP-28_W15.24mm
U4, U5: CY62256-70PC; DIP-28_W15.24mm
U6, U7: 74LS138; DIP-16_W7.62mm
U8: 74LS139; DIP-16_W7.62mm
U9, U12: 74HC00; DIP-14_W7.62mm
U10, U25, U26, U27: 74HC02; DIP-14_W7.62mm
U11: 74AHC04; DIP-14_W7.62mm
U13, U21: 74LS08; DIP-14_W7.62mm
U14, U15: 74LS27; DIP-14_W7.62mm
U16, U17: 74LS173; DIP-16_W7.62mm
U18, U19, U20: 74HC245; DIP-20_W7.62mm
U22: 74LS86; DIP-14_W7.62mm
U23: 74LS163; DIP-16_W7.62mm
U24: 74LS109; DIP-16_W7.62mm
U28: LMC555xN; DIP-8_W7.62mm
U29: 74LS148; DIP-16_W7.62mm
X1: TFT660; Oscillator_DIP-8

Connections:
/AddressDecoding/CTLREGB: U11.6, U16.9 (E1), U17.9 (E1)
/AddressDecoding/HB0: U8.14 (A0), U16.5 (Q2)
/AddressDecoding/HB1: U8.13 (A1), U16.6 (Q3)
/AddressDecoding/LB0: U8.2 (A0), U16.3 (Q0)
/AddressDecoding/LB1: U8.3 (A1), U16.4 (Q1)
/AddressDecoding/RIO: U10.3, U10.6, U11.3, U17.6 (Q3)
A0: U1.9 (A0), U2.38 (RS0), U3.10 (A0), U4.10 (A0), U5.10 (A0), U15.13, U19.9 (A7)
A1: U1.10 (A1), U2.37 (RS1), U3.9 (A1), U4.9 (A1), U5.9 (A1), U15.1, U19.8 (A6)
A2: U1.11 (A2), U2.36 (RS2), U3.8 (A2), U4.8 (A2), U5.8 (A2), U15.2, U19.7 (A5)
A3: U1.12 (A3), U2.35 (RS3), U3.7 (A3), U4.7 (A3), U5.7 (A3), U15.3, U19.6 (A4)
A4: U1.13 (A4), U3.6 (A4), U4.6 (A4), U5.6 (A4), U15.4, U19.5 (A3)
A5: U1.14 (A5), U3.5 (A5), U4.5 (A5), U5.5 (A5), U15.5, U19.4 (A2)
A6: U1.15 (A6), U3.4 (A6), U4.4 (A6), U5.4 (A6), U14.13, U19.3 (A1)
A7: U1.16 (A7), U3.3 (A7), U4.3 (A7), U5.3 (A7), U14.1, U19.2 (A0)
A8: U1.17 (A8), U3.25 (A8), U4.25 (A8), U5.25 (A8), U7.1 (A0), U14.2, U18.2 (A0)
A9: U1.18 (A9), U3.24 (A9), U4.24 (A9), U5.24 (A9), U7.2 (A1), U14.3, U18.3 (A1)
A10: U1.19 (A10), U3.21 (A10), U4.21 (A10), U5.21 (A10), U7.3 (A2), U14.4, U18.4 (A2)
A11: U1.20 (A11), U3.23 (A11), U4.23 (A11), U5.23 (A11), U7.4 (E1), U9.10, U14.5, U18.5 (A3)
A12: U1.22 (A12), U3.2 (A12), U4.2 (A12), U5.2 (A12), U6.1 (A0), U18.6 (A4)
A13: U1.23 (A13), U3.26 (A13), U4.26 (A13), U5.26 (A13), U6.2 (A1), U18.7 (A5)
A14: U1.24 (A14), U3.1 (A14), U4.1 (A14), U5.1 (A14), U6.3 (A2), U9.4, U11.1, U18.8 (A6)
A15: U1.25 (A15), U6.5 (E2), U9.2, U9.5, U10.9, U18.9 (A7)
AE0: J1.42, J2.42, J3.42, J4.42, J5.42, J6.42, J7.42, RN3.9 (R8), U19.11 (B7)
AE1: J1.40, J2.40, J3.40, J4.40, J5.40, J6.40, J7.40, RN3.8 (R7), U19.12 (B6)
AE2: J1.38, J2.38, J3.38, J4.38, J5.38, J6.38, J7.38, RN3.7 (R6), U19.13 (B5)
AE3: J1.36, J2.36, J3.36, J4.36, J5.36, J6.36, J7.36, RN3.6 (R5), U19.14 (B4)
AE4: J1.34, J2.34, J3.34, J4.34, J5.34, J6.34, J7.34, RN3.5 (R4), U19.15 (B3)
AE5: J1.32, J2.32, J3.32, J4.32, J5.32, J6.32, J7.32, RN3.4 (R3), U19.16 (B2)
AE6: J1.30, J2.30, J3.30, J4.30, J5.30, J6.30, J7.30, RN3.3 (R2), U19.17 (B1)
AE7: J1.28, J2.28, J3.28, J4.28, J5.28, J6.28, J7.28, RN3.2 (R1), U19.18 (B0)
AE8: J1.20, J2.20, J3.20, J4.20, J5.20, J6.20, J7.20, RN2.2 (R1), U18.18 (B0)
AE9: J1.18, J2.18, J3.18, J4.18, J5.18, J6.18, J7.18, RN2.3 (R2), U18.17 (B1)
AE10: J1.16, J2.16, J3.16, J4.16, J5.16, J6.16, J7.16, RN2.4 (R3), U18.16 (B2)
AE11: J1.14, J2.14, J3.14, J4.14, J5.14, J6.14, J7.14, RN2.5 (R4), U18.15 (B3)
AE12: J1.12, J2.12, J3.12, J4.12, J5.12, J6.12, J7.12, RN2.6 (R5), U18.14 (B4)
AE13: J1.10, J2.10, J3.10, J4.10, J5.10, J6.10, J7.10, RN2.7 (R6), U18.13 (B5)
AE14: J1.8, J2.8, J3.8, J4.8, J5.8, J6.8, J7.8, RN2.8 (R7), U18.12 (B6)
AE15: J1.6, J2.6, J3.6, J4.6, J5.6, J6.6, J7.6, RN2.9 (R8), U18.11 (B7)
CA1: J1.60, J2.60, J3.60, J4.60, J5.60, J6.60, J7.60, J10.1, U2.40 (CA1)
CA2: J1.59, J2.59, J3.59, J4.59, J5.59, J6.59, J7.59, J10.2, JP7.3 (B), U2.39 (CA2)
CB1: J1.62, J2.62, J3.62, J4.62, J5.62, J6.62, J7.62, J10.3, U2.18 (CB1)
CB2: J1.61, J2.61, J3.61, J4.61, J5.61, J6.61, J7.61, J10.4, U2.19 (CB2)
CLKDIV: J1.11, J2.11, J3.11, J4.11, J5.11, J6.11, J7.11, U27.13
CLKOSC: J1.7, J2.7, J3.7, J4.7, J5.7, J6.7, J7.7, U27.4
CPULED: R6.2, U17.3 (Q0)
CPUSPK: JP8.3 (B), U17.4 (Q1)
D0: U1.33 (D0), U2.33 (D0), U3.11 (D0), U4.11 (Q0), U5.11 (Q0), U17.14 (D0), U20.2 (A0)
D1: U1.32 (D1), U2.32 (D1), U3.12 (D1), U4.12 (Q1), U5.12 (Q1), U17.13 (D1), U20.3 (A1)
D2: U1.31 (D2), U2.31 (D2), U3.13 (D2), U4.13 (Q2), U5.13 (Q2), U17.12 (D2), U20.4 (A2)
D3: U1.30 (D3), U2.30 (D3), U3.15 (D3), U4.15 (Q3), U5.15 (Q3), U17.11 (D3), U20.5 (A3)
D4: U1.29 (D4), U2.29 (D4), U3.16 (D4), U4.16 (Q4), U5.16 (Q4), U16.14 (D0), U20.6 (A4)
D5: U1.28 (D5), U2.28 (D5), U3.17 (D5), U4.17 (Q5), U5.17 (Q5), U16.13 (D1), U20.7 (A5)
D6: U1.27 (D6), U2.27 (D6), U3.18 (D6), U4.18 (Q6), U5.18 (Q6), U16.12 (D2), U20.8 (A6)
D7: U1.26 (D7), U2.26 (D7), U3.19 (D7), U4.19 (Q7), U5.19 (Q7), U16.11 (D3), U20.9 (A7)
DE0: J1.41, J2.41, J3.41, J4.41, J5.41, J6.41, J7.41, RN4.2 (R1), U20.18 (B0)
DE1: J1.39, J2.39, J3.39, J4.39, J5.39, J6.39, J7.39, RN4.3 (R2), U20.17 (B1)
DE2: J1.37, J2.37, J3.37, J4.37, J5.37, J6.37, J7.37, RN4.4 (R3), U20.16 (B2)
DE3: J1.35, J2.35, J3.35, J4.35, J5.35, J6.35, J7.35, RN4.5 (R4), U20.15 (B3)
DE4: J1.33, J2.33, J3.33, J4.33, J5.33, J6.33, J7.33, RN4.6 (R5), U20.14 (B4)
DE5: J1.31, J2.31, J3.31, J4.31, J5.31, J6.31, J7.31, RN4.7 (R6), U20.13 (B5)
DE6: J1.29, J2.29, J3.29, J4.29, J5.29, J6.29, J7.29, RN4.8 (R7), U20.12 (B6)
DE7: J1.27, J2.27, J3.27, J4.27, J5.27, J6.27, J7.27, RN4.9 (R8), U20.11 (B7)
EXTCLK: J1.52, J2.52, J3.52, J4.52, J5.52, J6.52, J7.52, JP9.3 (B)
EXTCTLB: J1.49, J2.49, J3.49, J4.49, J5.49, J6.49, J7.49, R1.2, U1.36 (BE), U18.1 (A->B), U19.1 (A->B), U22.1, U22.4
EXTH0B: J1.55, J2.55, J3.55, J4.55, J5.55, J6.55, J7.55, U8.10 (O2)
EXTH1B: J1.57, J2.57, J3.57, J4.57, J5.57, J6.57, J7.57, U8.9 (O3)
EXTL0B: J1.56, J2.56, J3.56, J4.56, J5.56, J6.56, J7.56, U8.6 (O2)
EXTL1B: J1.58, J2.58, J3.58, J4.58, J5.58, J6.58, J7.58, U8.7 (O3)
GND: C1.2, C2.2, C3.2, C4.2, C5.2, C6.2, C7.2, C8.2, C9.2, C10.2, C11.2, C12.2, C13.2, C14.2, C15.2, C16.2, C17.2, C18.2, C19.2, C20.2, C21.2, C22.2, C23.2, C24.2, C25.2, C26.2, C27.2, C28.2, C29.2, D1.1 (K), D2.1 (K), H1.1, H2.1, H3.1, H4.1, J0.2, J0.3, J1.1, J1.2, J1.21, J1.22, J1.25, J1.26, J1.45, J1.46, J1.63, J1.64, J2.1, J2.2, J2.21, J2.22, J2.25, J2.26, J2.45, J2.46, J2.63, J2.64, J3.1, J3.2, J3.21, J3.22, J3.25, J3.26, J3.45, J3.46, J3.63, J3.64, J4.1, J4.2, J4.21, J4.22, J4.25, J4.26, J4.45, J4.46, J4.63, J4.64, J5.1, J5.2, J5.21, J5.22, J5.25, J5.26, J5.45, J5.46, J5.63, J5.64, J6.1, J6.2, J6.21, J6.22, J6.25, J6.26, J6.45, J6.46, J6.63, J6.64, J7.1, J7.2, J7.21, J7.22, J7.25, J7.26, J7.45, J7.46, J7.63, J7.64, J8.10, J9.10, JP0.3 (B), JP1.3 (B), JP2.3 (B), JP3.3 (B), LS1.2, Q1.1 (S), Q2.1 (S), RN2.1 (common), RN3.1 (common), SW1.2, SW2.2, SW3.2, SW4.2, SW5.2, SW6.1, U1.21 (VSS), U2.1 (VSS), U3.14 (GND), U4.14 (GND), U5.14 (GND), U6.4 (E1), U6.8 (GND), U7.8 (GND), U8.8 (GND), U9.7 (GND), U10.7 (GND), U11.7 (GND), U12.7 (GND), U13.7 (GND), U14.7 (GND), U15.7 (GND), U16.1 (Oe1), U16.2 (Oe2), U16.8 (GND), U17.1 (Oe1), U17.2 (Oe2), U17.8 (GND), U18.10 (GND), U18.19 (CE), U19.10 (GND), U19.19 (CE), U20.10 (GND), U21.7 (GND), U22.7 (GND), U23.8 (GND), U24.8 (GND), U25.7 (GND), U26.7 (GND), U27.7 (GND), U28.1 (GND), U29.5 (EI), U29.8 (GND), X1.4 (GND)
HIRAMB: U5.20 (~CS), U13.6, U21.4
IO2B: J2.5, U7.13 (O2)
IO3B: J3.5, U7.12 (O3)
IO4B: J4.5, U7.11 (O4)
IO5B: J5.5, U7.10 (O5)
IO6B: J6.5, U7.9 (O6)
IO7B: J7.5, U7.7 (O7)
IOHB: J1.9, J2.9, J3.9, J4.9, J5.9, J6.9, J7.9, U9.8
IRQB: U1.4 (~IRQ), U13.11
IRQEXTB: J1.47, J2.47, J3.47, J4.47, J5.47, J6.47, J7.47, JP7.1 (A), R13.2, U13.12
LORAMB: U4.20 (~CS), U10.13, U21.5
MLB: J1.51, J2.51, J3.51, J4.51, J5.51, J6.51, J7.51, U1.5 (~ML)
NMIB: J1.48, J2.48, J3.48, J4.48, J5.48, J6.48, J7.48, R4.2, U1.6 (~NMI)
unnamed: D1.2 (A), R6.1
unnamed: D2.2 (A), R2.1
unnamed: J8.2, U2.2 (PA0)
unnamed: J8.3, U2.3 (PA1)
unnamed: J8.4, U2.4 (PA2)
unnamed: J8.5, U2.5 (PA3)
unnamed: J8.6, U2.6 (PA4)
unnamed: J8.7, U2.7 (PA5)
unnamed: J8.8, U2.8 (PA6)
unnamed: J8.9, U2.9 (PA7)
unnamed: J9.2, U2.10 (PB0)
unnamed: J9.3, U2.11 (PB1)
unnamed: J9.4, U2.12 (PB2)
unnamed: J9.5, JP4.1 (A), U2.13 (PB3)
unnamed: J9.6, JP5.1 (A), U2.14 (PB4)
unnamed: J9.7, JP6.1 (A), U2.15 (PB5)
unnamed: J9.8, U2.16 (PB6)
unnamed: J9.9, JP8.1 (A), U2.17 (PB7)
unnamed: JP0.2 (C), U23.3 (D0)
unnamed: JP1.2 (C), U23.4 (D1)
unnamed: JP2.2 (C), U23.5 (D2)
unnamed: JP3.2 (C), U23.6 (D3)
unnamed: JP4.2 (B), U29.9 (S0)
unnamed: JP5.2 (B), U29.7 (S1)
unnamed: JP6.2 (B), U29.6 (S2)
unnamed: JP7.2 (C), Q2.3 (D), R12.2
unnamed: JP8.2 (C), U21.2
unnamed: JP9.1 (A), X1.5 (OUT)
unnamed: JP9.2 (C), U23.2 (CP), U24.4 (C), U24.12 (C), U25.3, U27.2, U27.3
unnamed: LS1.1, R5.1
unnamed: Q1.2 (G), R10.2
unnamed: Q2.2 (G), R11.2
unnamed: R5.2, U21.3
unnamed: RN1.2 (R1), SW1.1, U29.4 (I7)
unnamed: RN1.3 (R2), SW2.1, U29.3 (I6)
unnamed: RN1.4 (R3), SW3.1, U29.2 (I5)
unnamed: RN1.5 (R4), SW4.1, U29.1 (I4)
unnamed: RN1.6 (R5), SW5.1, U29.13 (I3)
unnamed: U2.21 (~IRQ), U13.13
unnamed: U6.15 (O0), U14.9
unnamed: U6.9 (O6), U7.5 (E2), U10.2, U10.5
unnamed: U7.6 (E3), U11.4
unnamed: U8.1 (E), U9.3
unnamed: U8.4 (O0), U13.2
unnamed: U8.5 (O1), U13.5
unnamed: U8.15 (E), U9.6
unnamed: U8.12 (O0), U13.1
unnamed: U8.11 (O1), U13.4
unnamed: U10.1, U10.8
unnamed: U9.9, U10.4
unnamed: U10.10, U10.11, U10.12
unnamed: U9.1, U11.2
unnamed: U11.5, U14.8
unnamed: U11.10, U12.10, U12.13
unnamed: U12.1, U14.12
unnamed: U12.2, U14.6
unnamed: U12.3, U14.10
unnamed: U12.4, U15.6
unnamed: U12.5, U15.12
unnamed: U12.6, U14.11
unnamed: U11.8, U16.15 (Mr), U17.15 (Mr)
unnamed: U20.1 (A->B), U22.3
unnamed: U20.19 (CE), U22.6
unnamed: U21.11, U22.5
unnamed: U21.6, U21.12
unnamed: U21.8, U21.13
unnamed: U22.12, U23.15 (TC), U24.2 (J)
unnamed: U22.11, U23.9 (~PE), U24.3 (~K), U25.11
unnamed: U24.6 (Q), U25.6, U25.12, U27.8, U27.9
unnamed: U24.13 (~K), U24.14 (J), U26.4
unnamed: U24.10 (Q), U25.5, U26.3
unnamed: U24.9 (~Q), U25.2
unnamed: U25.1, U25.8
unnamed: U25.4, U25.9
unnamed: U25.13, U26.2, U26.11, U26.12
unnamed: U26.1, U26.5
unnamed: U26.6, U26.10
unnamed: U26.8, U26.13
unnamed: U27.1, U27.5, U27.6
unnamed: U27.10, U27.11, U27.12
unnamed: C28.1, U28.5 (CV)
unnamed: C29.1, R8.2, U28.6 (THR), U28.7 (DIS)
unnamed: R10.1, U28.3 (Q)
unnamed: C27.1, R7.2, SW6.2, U28.2 (TR)
unnamed: R11.1, U29.15 (EO)
PHI1: J1.19, J2.19, J3.19, J4.19, J5.19, J6.19, J7.19, U1.3 (ϕ1), U16.7 (Cp), U17.7 (Cp)
PHI2: J1.15, J2.15, J3.15, J4.15, J5.15, J6.15, J7.15, U1.37 (ϕ0), U2.25 (ϕ2), U12.9, U12.12, U25.10
RDY: J1.50, J2.50, J3.50, J4.50, J5.50, J6.50, J7.50, R3.2, U1.2 (RDY)
ROMB: U3.20 (~CS), U13.3, U21.10
RSTB: J1.17, J2.17, J3.17, J4.17, J5.17, J6.17, J7.17, Q1.3 (D), R9.2, U1.40 (~RES), U2.34 (~RES), U11.9
RW: J1.13, J2.13, J3.13, J4.13, J5.13, J6.13, J7.13, U1.34 (R/~W), U2.22 (R/~W), U11.11, U11.13, U16.10 (E2), U17.10 (E2), U22.2
RWB: U3.22 (~OE), U4.22 (~OE), U5.22 (~OE), U11.12
SELCLK: U17.5 (Q2), U26.9
SYNC: J1.54, J2.54, J3.54, J4.54, J5.54, J6.54, J7.54, U1.7 (SYNC)
TFTB: J1.5, U7.14 (O1)
VDD: C1.1, C2.1, C3.1, C4.1, C5.1, C6.1, C7.1, C8.1, C9.1, C10.1, C11.1, C12.1, C13.1, C14.1, C15.1, C16.1, C17.1, C18.1, C19.1, C20.1, C21.1, C22.1, C23.1, C24.1, C25.1, C26.1, J0.1, J1.3, J1.4, J1.23, J1.24, J1.43, J1.44, J2.3, J2.4, J2.23, J2.24, J2.43, J2.44, J3.3, J3.4, J3.23, J3.24, J3.43, J3.44, J4.3, J4.4, J4.23, J4.24, J4.43, J4.44, J5.3, J5.4, J5.23, J5.24, J5.43, J5.44, J6.3, J6.4, J6.23, J6.24, J6.43, J6.44, J7.3, J7.4, J7.23, J7.24, J7.43, J7.44, J8.1, J9.1, J11.2, JP0.1 (A), JP1.1 (A), JP2.1 (A), JP3.1 (A), R1.1, R2.2, R3.1, R4.1, R7.1, R8.1, R9.1, R12.1, R13.1, RN1.1 (common), RN4.1 (common), U1.8 (VDD), U2.20 (VCC), U2.24 (CS1), U3.27 (~WE), U3.28 (VCC), U4.28 (VCC), U5.28 (VCC), U6.6 (E3), U6.16 (VCC), U7.16 (VCC), U8.16 (VCC), U9.12, U9.13, U9.14 (VCC), U10.14 (VCC), U11.14 (VCC), U12.14 (VCC), U13.9, U13.10, U13.14 (VCC), U14.14 (VCC), U15.9, U15.10, U15.11, U15.14 (VCC), U16.16 (VCC), U17.16 (VCC), U18.20 (VCC), U19.20 (VCC), U20.20 (VCC), U21.1, U21.14 (VCC), U22.9, U22.10, U22.13, U22.14 (VCC), U23.1 (~MR), U23.7 (CEP), U23.10 (CET), U23.16 (VCC), U24.1 (~R), U24.5 (~S), U24.11 (~S), U24.15 (~R), U24.16 (VCC), U25.14 (VCC), U26.14 (VCC), U27.14 (VCC), U28.4 (R), U28.8 (VCC), U29.16 (VCC), X1.8 (Vcc)
VIAB: U2.23 (~CS2), U7.15 (O0), U21.9
VPB: J1.53, J2.53, J3.53, J4.53, J5.53, J6.53, J7.53, U1.1 (~VP)
WRAMB: U4.27 (~WE), U5.27 (~WE), U12.8
WTFTB: J11.1, U12.11
